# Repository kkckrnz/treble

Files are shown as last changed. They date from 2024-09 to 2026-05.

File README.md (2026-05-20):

# Treble
Treble keyboard is a 42 key, low profile choc v1, monoblock, moderate column staggered, wireless/wired mechanical keyboard powered by pro micro compatible MCU board. It is designed with [ergogen](https://github.com/ergogen/ergogen), the ergonomic keyboard generator.

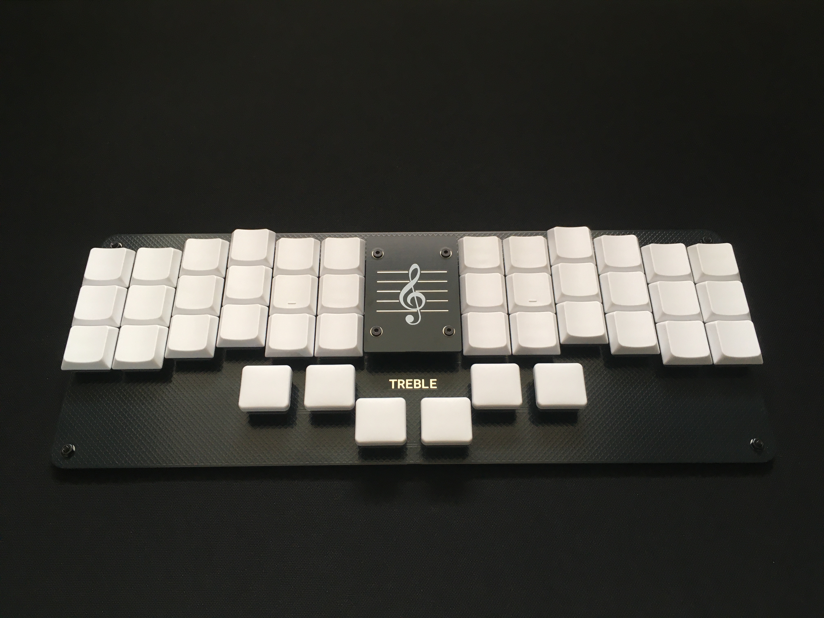
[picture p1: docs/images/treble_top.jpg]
treble_top

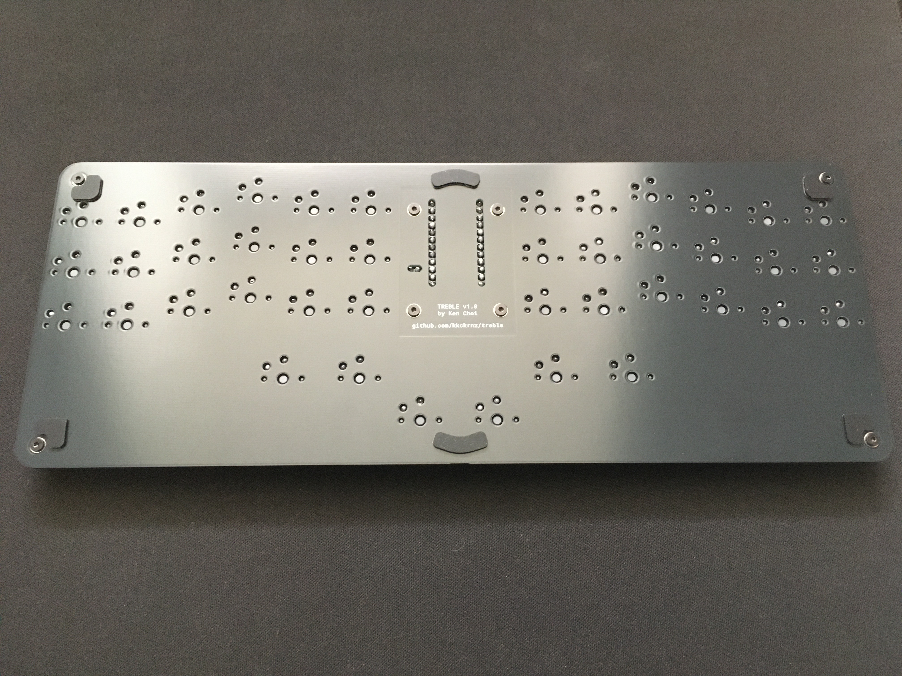
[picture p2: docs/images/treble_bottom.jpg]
treble_bottom

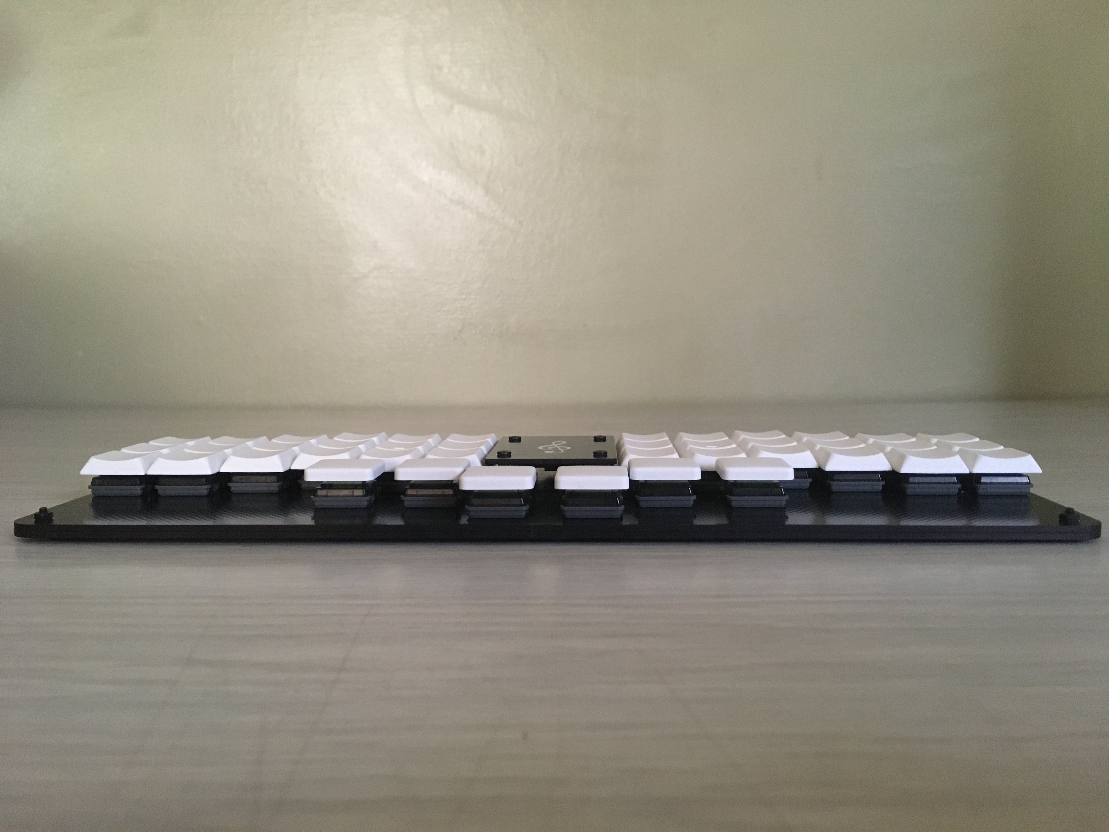
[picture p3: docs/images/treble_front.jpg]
treble_front


The sandwich PCB design concept came from [Horizon keyboard](https://github.com/skarrmann/horizon). Bottom plate cutouts for through-hole pins makes it so that keyboard can be put on any surface, and the cover plate hides all the other internal components. Overall, this design makes the keyboard clean, low profile and look more finished without needing a dedicated case.

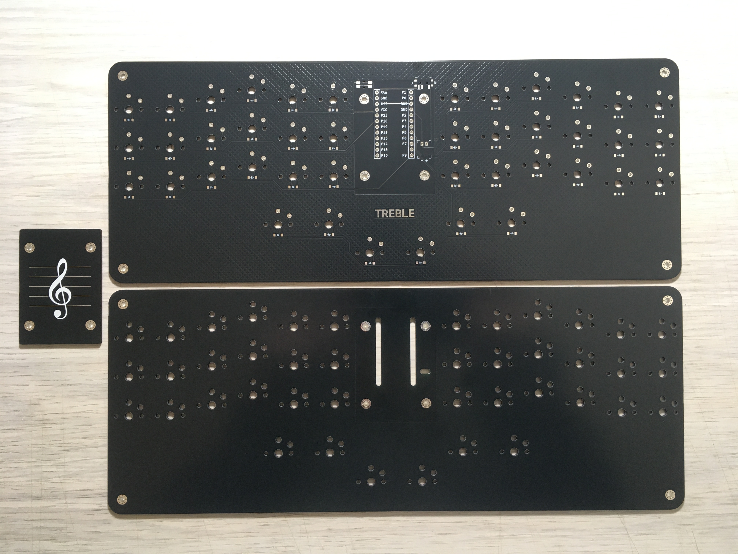
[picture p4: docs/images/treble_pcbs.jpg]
treble_pcbs


## Features
- Rectangular design for improved stability; easier to place on your lap or a laptop
- Low profile: total height is about 15mm tall
- Compact: overall size smaller than Apple Magic Keyboard
- Column staggered: mildly staggered so it's easy transition from row staggered keyboard yet it provides more comfortable typing experience
- 6 thumb keys: enough thumb keys for switching to different layers
- PCBs-for-case design
- Wireless/Wired depending on your preference

## Bill of Materials

| **Part** | **Quantity** | **Notes** |
| --- | --- | --- |
| **Main PCB** | 1 | treble_vx.x.zip |
| **Cover plate PCB** | 1 | treble_vx.x_cover_plate.zip |
| **Bottom plate PCB** | 1 | treble_vx.x_bottom_plate.zip |
| **MCU board** | 1 | Pro Micro compatible board |
| **Machine Sockets** | 2 | Mill-Max 310 |
| **Machine Socket Pins** | 24 | Mill-Max 3320 |
| **Key switches** | 42 | Choc v1 |
| **Keycaps** | 42 | Choc v1 compatible |
| **Diodes** | 42 | 1N4148 SOD-123 |
| **Reset switch** | 1 | EVQPU |
| **Power switch** | 1 | MSK-12C02 |
| **JST connector (female)** | 1 | S2B-PH-K-S |
| **JST connector (male)** | 1 | |
| **Battery** | 1 | 301230 110mAh 3.7V LiPo |
| **M2 6mm screws** | 12 | |
| **M2 nuts** | 4 | |
| **M2 8mm standoffs (female-female)** | 4 | |
| **Rubber feet** | 6 | |

- Male JST connector is only needed if the battery doesn't come with it
- You don't need Power switch, JST connector, and Battery if you build a wired keyboard

## Printable Treble
Download [Treble-A4.pdf](/docs/treble-A4.pdf) and print it (scale at 100%). Test the keyboard layout with your own hands.

## PCB order guide
1. Download gerber files from *Releases* on sidebar
2. Submit gerber files to PCB manufacturer
3. Select manufacturing options
4. Order

### JLCPCB manufacturing options
Most options are default. Changed options in *italic*:
- Base Material: FR-4
- Layers: 2
- Dimensions: (automatically filled in)
- PCB Qty: 5
- Product Type: Industrial/Consumer electronics
- Different Design: 1
- Delivery Format: Single PCB
- PCB Thickness: 1.6
- PCB Color: *Black*
- Silkscreen: White
- Surface Finish: *LeadFree HASL*
- Outer Copper Weight: 1 oz
- Via Covering: Tented
- Min via hole size/diameter: 0.3mm/(0.4/0.45mm)
- Board Outline Tolerance: ±0.2mm(Regular)
- Confirm Production file: No
- Mark on PCB: *Remove Mark*
- Electrical Test: Flying Probe Fully Test
- Gold Fingers: No
- Castellated Holes: No
- Edge Plating: No

I recommend **LeadFree HASL** option because you will be handling the keyboard directly without a case. Pick the PCB color of your choice. **Remove Mark** so you won't see random number printed on the PCB.

## Firmware
### ZMK
1. Setup GitHub Repo by following [ZMK documentation](https://zmk.dev/docs/user-setup#github-repo)
2. Setup User Config by following [ZMK documentation](https://zmk.dev/docs/user-setup#user-config-setup-script)	
3. Copy & Paste `/boards`, `/config`, and `build.yaml` from [zmk-config folder](/firmware/zmk-config) in this repo to zmk-config folder in your repo
4. Customise `treble.keymap` and `treble.conf` files in `/config` however you like it. Then push changes to your repo
```
git add .
git commit -m "commit message"
git push -u origin main
```
5. Install firmware by following [ZMK documentation](https://zmk.dev/docs/user-setup#installing-the-firmware)

- If you use MCU board other than nice!nano v2, then you will have to edit `build.yaml` file.
- [Precompiled firmware](/firmware/treble-nice_nano_v2-zmk.uf2.zip) is also available.
- There's [video guide](https://www.youtube.com/watch?v=O_urj-rF3bQ) by Joe Scotto if you would rather setup from scratch.

### Other Firmware
Since the keyboard is pro micro compatible it should be able to run QMK & KMK as well (not tested).

## Build guide
Follow [Build Guide](docs/treble_build_guide.md) to assemble the keyboard.

## Feedback
For any issues or questions please let me know.

If you have built and enjoyed the keyboard, consider supporting me.

Future development ideas:
- QMK & KMK firmware
- Hot swap switch support
- Low profile case
- MX version



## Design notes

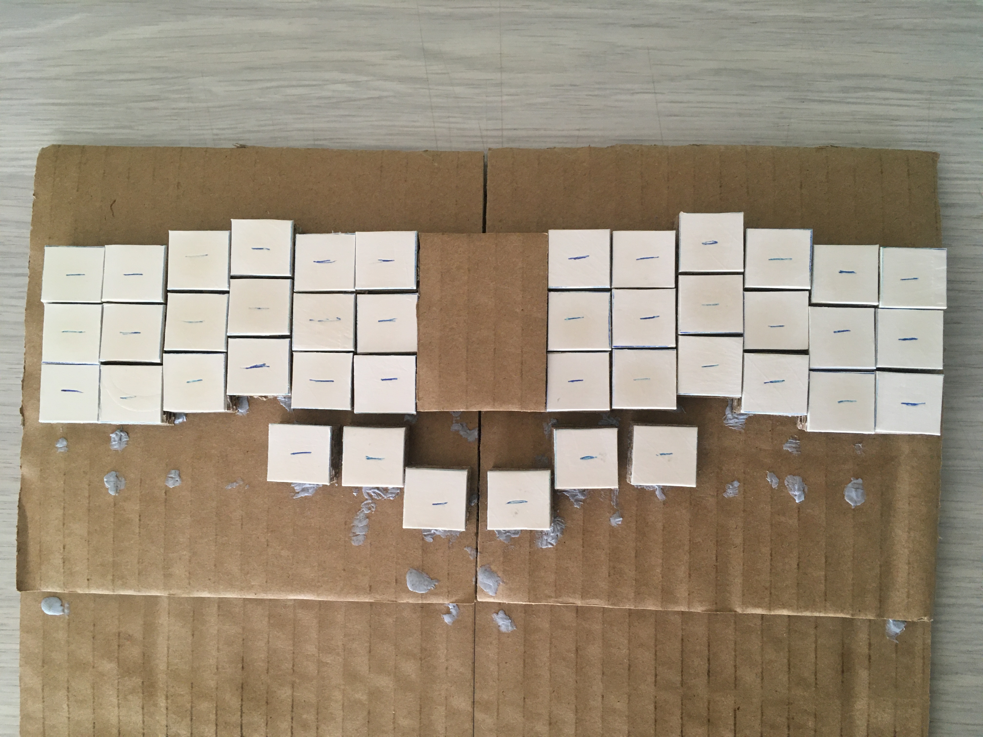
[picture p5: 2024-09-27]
docs/images/prototype.jpg

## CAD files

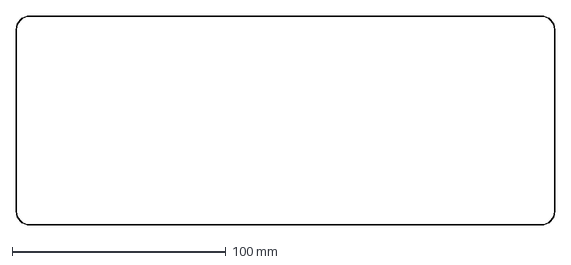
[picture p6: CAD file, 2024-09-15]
ergogen/output/outlines/board.dxf
252.0 x 97.8 mm

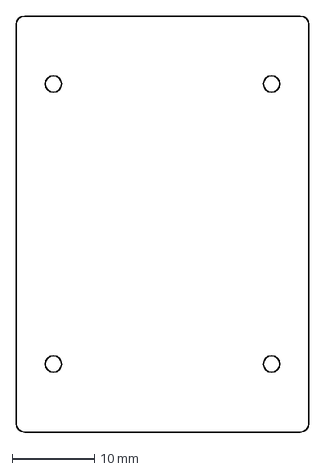
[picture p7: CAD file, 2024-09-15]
ergogen/output/outlines/cover_plate_view.dxf
35.5 x 50.5 mm

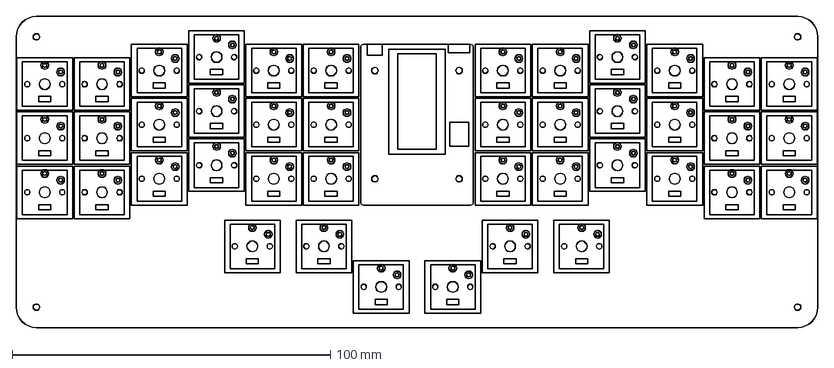
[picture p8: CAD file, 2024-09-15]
ergogen/output/outlines/everything.dxf
252.0 x 97.8 mm

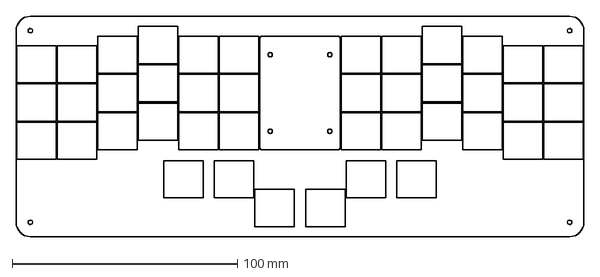
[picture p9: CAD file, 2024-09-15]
ergogen/output/outlines/keyboard_view.dxf
252.0 x 97.8 mm

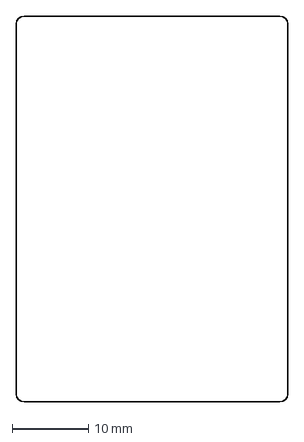
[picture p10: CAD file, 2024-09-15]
ergogen/output/outlines/cover.dxf
35.5 x 50.5 mm

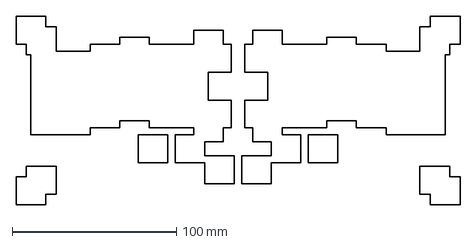
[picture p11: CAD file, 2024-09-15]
ergogen/output/outlines/raw.dxf
270.0 x 114.8 mm

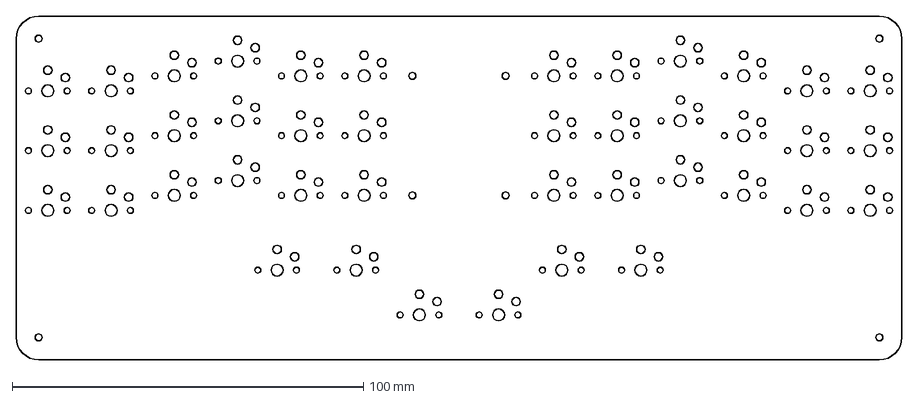
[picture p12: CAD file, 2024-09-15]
ergogen/output/outlines/bottom_plate_view.dxf
252.0 x 97.8 mm

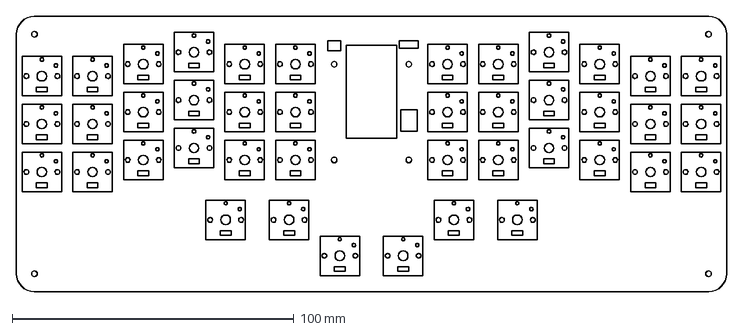
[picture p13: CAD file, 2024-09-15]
ergogen/output/outlines/board_view.dxf
252.0 x 97.8 mm

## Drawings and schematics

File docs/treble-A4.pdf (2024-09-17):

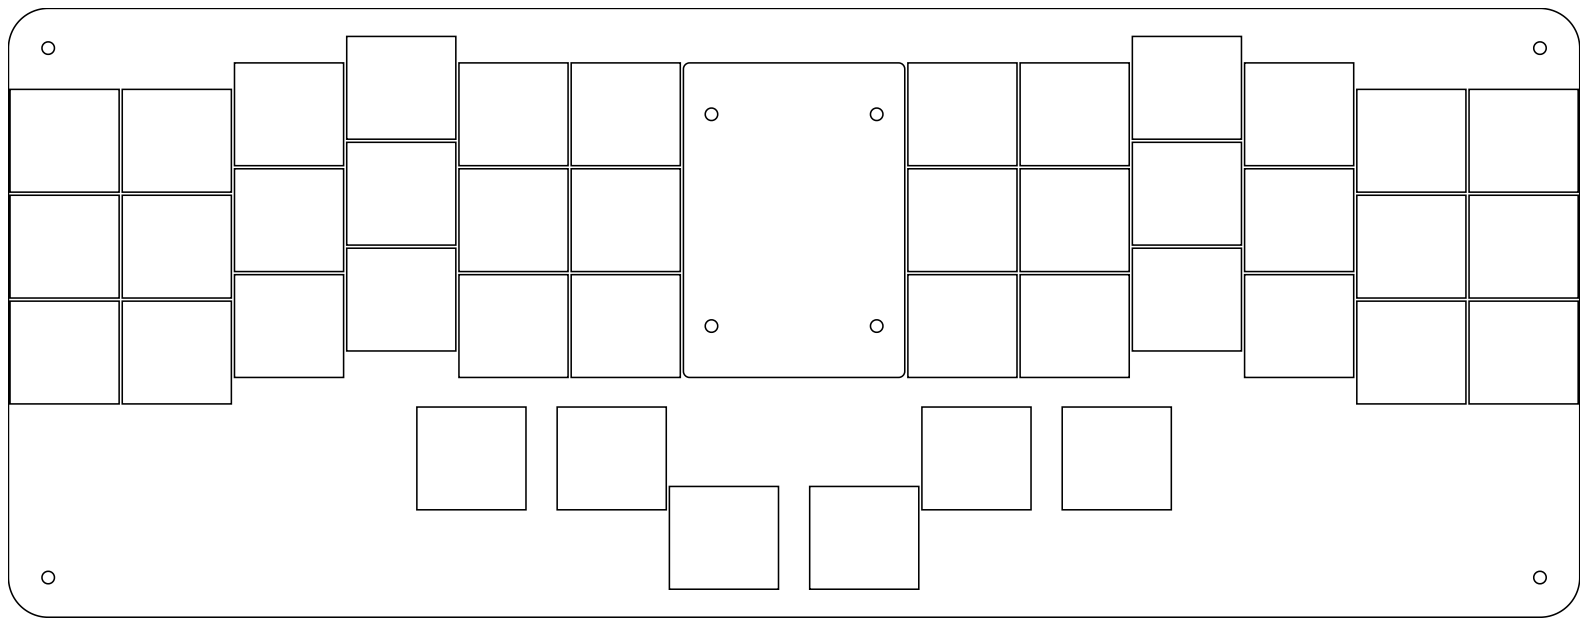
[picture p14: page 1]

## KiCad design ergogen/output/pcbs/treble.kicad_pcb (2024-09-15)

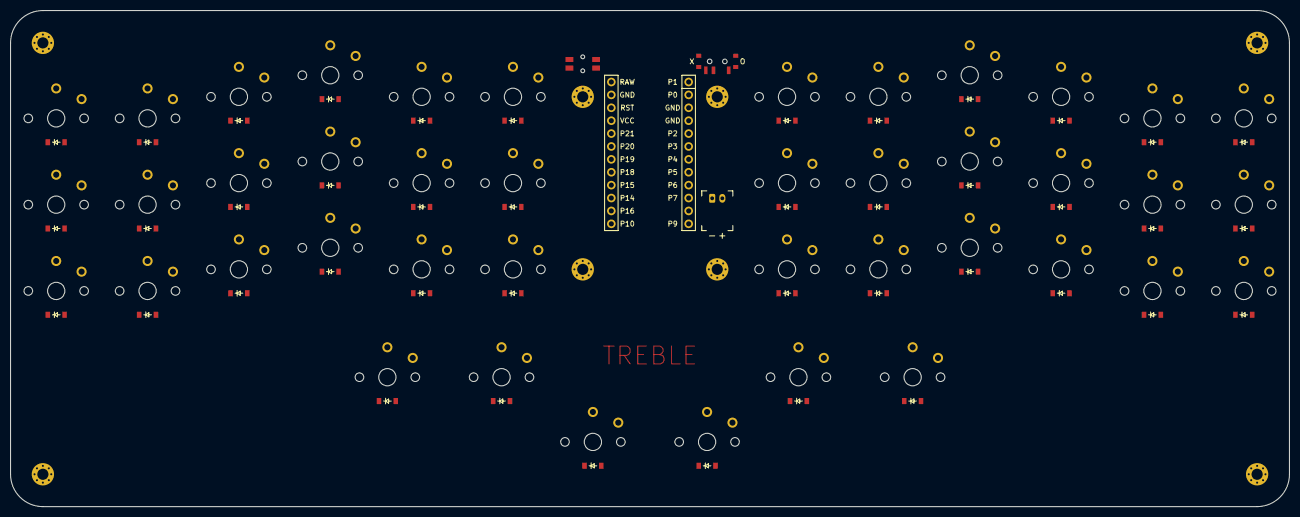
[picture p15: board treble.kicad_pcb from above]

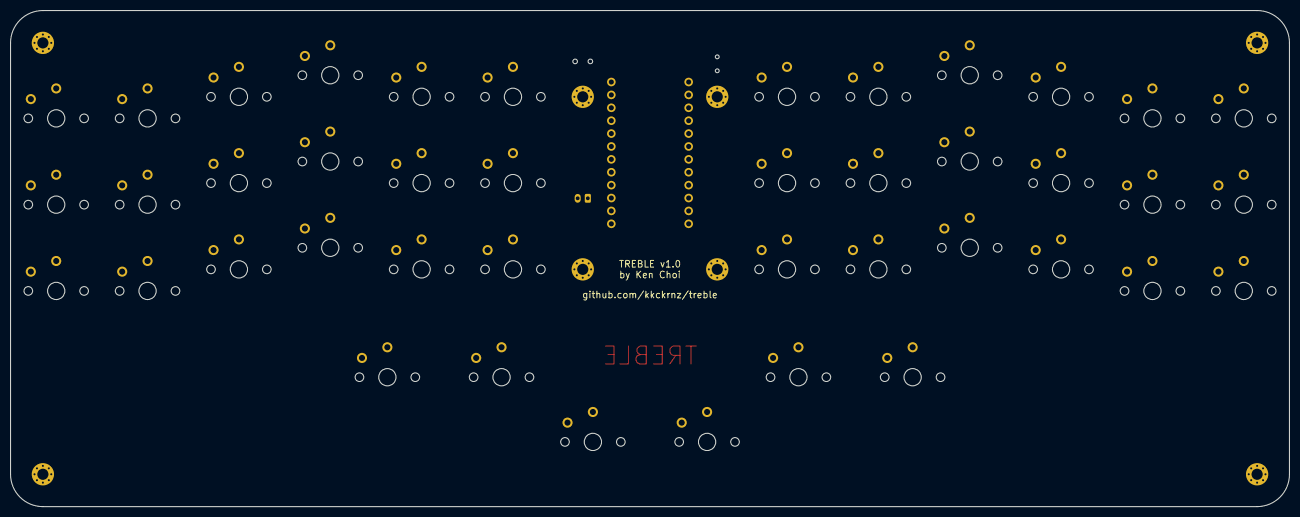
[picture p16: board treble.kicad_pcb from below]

Board: 2 copper layers, 252.0 x 97.8 mm, 141 parts (42 on the bottom side), 59 nets, no tracks yet.

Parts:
CJ1: CutoutMCU
CM1: CutoutMCU
CS1, CS2, CS3, CS4, CS5, CS6, CS7, CS8, CS9, CS10, CS11, CS12, CS13, CS14, CS15, CS16, CS17, CS18, CS19, CS20, CS21, CS22, CS23, CS24, CS25, CS26, CS27, CS28, CS29, CS30, CS31, CS32, CS33, CS34, CS35, CS36, CS37, CS38, CS39, CS40, CS41, CS42: CutoutSwitch
D1, D2, D3, D4, D5, D6, D7, D8, D9, D10, D11, D12, D13, D14, D15, D16, D17, D18, D19, D20, D21, D22, D23, D24, D25, D26, D27, D28, D29, D30, D31, D32, D33, D34, D35, D36, D37, D38, D39, D40, D41, D42: diode_tht_sod123
H1, H2, H3, H4, H5, H6, H7, H8: MountingHole_2.2mm_M2_Pad_Via
JST1: battery_connector_jst_ph_2
MCU1: mcu_nice_nano
PWR1: power_switch_smd_side
RA1: RuledArea
RST1: reset_switch_smd_side
S1, S2, S3, S4, S5, S6, S7, S8, S9, S10, S11, S12, S13, S14, S15, S16, S17, S18, S19, S20, S21, S22, S23, S24, S25, S26, S27, S28, S29, S30, S31, S32, S33, S34, S35, S36, S37, S38, S39, S40, S41, S42: switch_choc_v1_v2

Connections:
BAT_P: JST1.2, PWR1.1
GND: JST1.1, MCU1.3, MCU1.4, MCU1.23, RST1.1, RST1.3
P5: D24.1, D27.1, D30.1, D33.1, D36.1, D39.1, MCU1.8
P6: D23.1, D26.1, D29.1, D32.1, D35.1, D38.1, MCU1.9
P7: D22.1, D25.1, D28.1, D31.1, D34.1, D37.1, MCU1.10
P8: D19.1, D20.1, D21.1, D40.1, D41.1, D42.1, MCU1.11
P9: D1.1, D4.1, D7.1, D10.1, D13.1, D16.1, MCU1.12
P10: MCU1.13, S1.2, S2.2, S3.2, S37.2, S38.2, S39.2, S42.2
P14: MCU1.15, S7.2, S8.2, S9.2, S31.2, S32.2, S33.2, S40.2
P15: MCU1.16, S10.2, S11.2, S12.2, S19.2, S28.2, S29.2, S30.2
P16: MCU1.14, S4.2, S5.2, S6.2, S34.2, S35.2, S36.2, S41.2
P18: MCU1.17, S13.2, S14.2, S15.2, S20.2, S25.2, S26.2, S27.2
P19: MCU1.18, S16.2, S17.2, S18.2, S21.2, S22.2, S23.2, S24.2
P20: D2.1, D5.1, D8.1, D11.1, D14.1, D17.1, MCU1.19
P21: D3.1, D6.1, D9.1, D12.1, D15.1, D18.1, MCU1.20
RAW: MCU1.24, PWR1.2
RST: MCU1.22, RST1.2, RST1.4
home_thumb: D20.2, S20.1
index_bottom: D13.2, S13.1
index_home: D14.2, S14.1
index_top: D15.2, S15.1
inner_bottom: D16.2, S16.1
inner_home: D17.2, S17.1
inner_thumb: D19.2, S19.1
inner_top: D18.2, S18.1
middle_bottom: D10.2, S10.1
middle_home: D11.2, S11.1
middle_top: D12.2, S12.1
mirror_home_thumb: D41.2, S41.1
mirror_index_bottom: D34.2, S34.1
mirror_index_home: D35.2, S35.1
mirror_index_top: D36.2, S36.1
mirror_inner_bottom: D37.2, S37.1
mirror_inner_home: D38.2, S38.1
mirror_inner_thumb: D40.2, S40.1
mirror_inner_top: D39.2, S39.1
mirror_middle_bottom: D31.2, S31.1
mirror_middle_home: D32.2, S32.1
mirror_middle_top: D33.2, S33.1
mirror_outer_bottom: D22.2, S22.1
mirror_outer_home: D23.2, S23.1
mirror_outer_thumb: D42.2, S42.1
mirror_outer_top: D24.2, S24.1
mirror_pinky_bottom: D25.2, S25.1
mirror_pinky_home: D26.2, S26.1
mirror_pinky_top: D27.2, S27.1
mirror_ring_bottom: D28.2, S28.1
mirror_ring_home: D29.2, S29.1
mirror_ring_top: D30.2, S30.1
outer_bottom: D1.2, S1.1
outer_home: D2.2, S2.1
outer_thumb: D21.2, S21.1
outer_top: D3.2, S3.1
pinky_bottom: D4.2, S4.1
pinky_home: D5.2, S5.1
pinky_top: D6.2, S6.1
ring_bottom: D7.2, S7.1
ring_home: D8.2, S8.1
ring_top: D9.2, S9.1

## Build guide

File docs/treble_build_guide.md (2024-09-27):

# Treble Build Guide
## Build overview
1. SMD components
2. Through-hole components
3. Testing
4. Key switches & Keycaps
5. Assembly

## General Tips
- Pads and pins connected to GND and Battery Positive are more difficult to solder. Consider increasing temperature for those pads and pins.
- Flux helps especially on those hard-to-solder pins and pads.
- I used 0.3mm solder wire for SMD components and 0.8mm wire for the rest.

## 1. SMD components
### Diodes
1. Add solder to one pad of the PCB
2. Make sure the line on diode marking is aligned with the line marked on the PCB
3. Hold the diode in place using a pair of tweezers
4. Apply heat on the pad to connect diode to the PCB
5. Add solder to the other pad

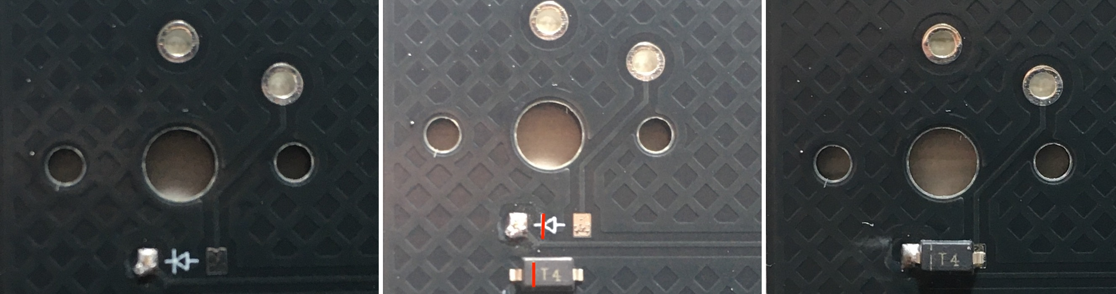
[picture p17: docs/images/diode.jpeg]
diode


### Power & Reset switch
1. Add solder to the pads on one side
2. Hold the switch in place using a pair of tweezers
3. Heat the pads to connect the switch to the PCB
4. Solder the rest of the pads

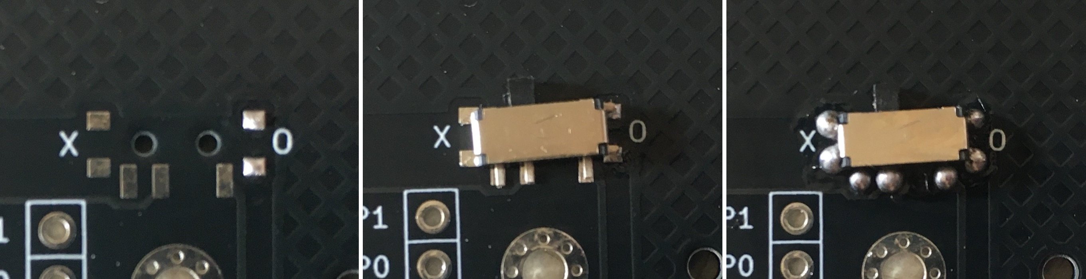
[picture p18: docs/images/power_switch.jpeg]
power_switch


## 2. Through-hole components
### MCU board
Soldering to the PCB:
1. Insert socket into the top of the PCB
2. Flip the PCB and solder the top and bottom pins
3. Solder the rest of the pins

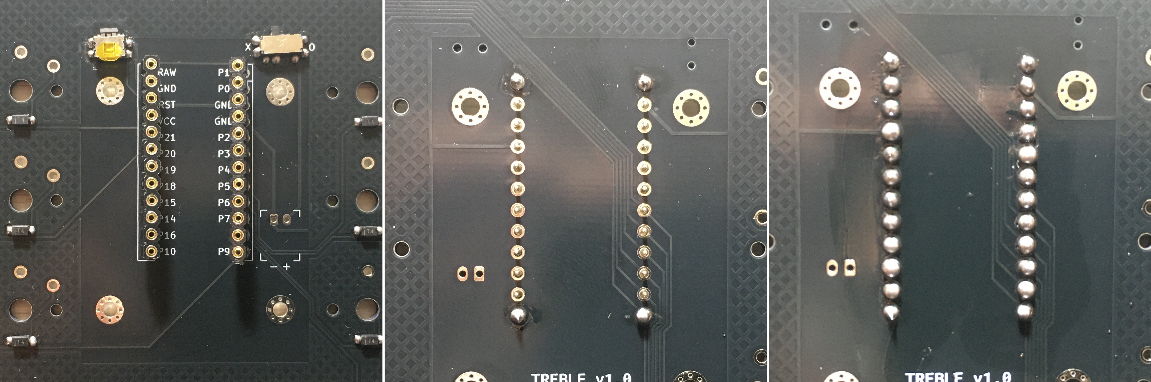
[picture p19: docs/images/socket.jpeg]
socket


Insert pins:
1. Place kapton tape over the top of each socket
2. Poke pins through the tape
3. Pins sit about 2mm above the top of the socket when fully inserted.

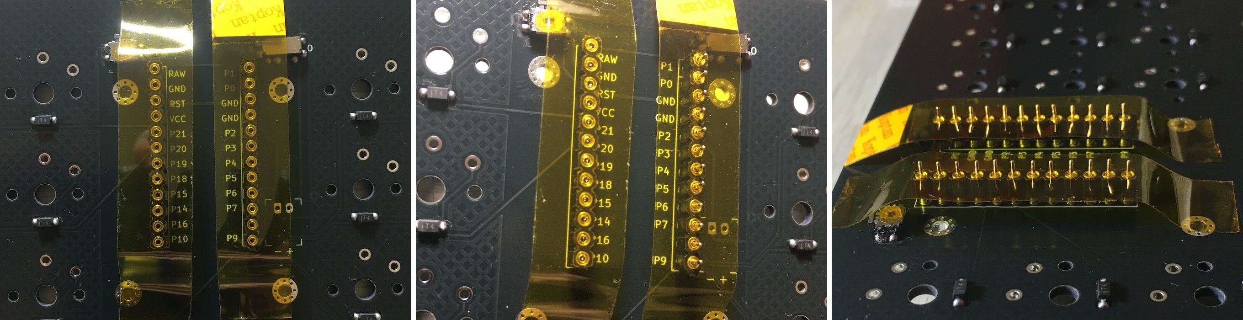
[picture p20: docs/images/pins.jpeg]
pins


Solder MCU board:
1. Place MCU face down on the pins
2. Ensure B+/B- do not have pins in them
3. Solder each corner pin
4. Solder the rest of the pins
5. Remove MCU and kapton tape

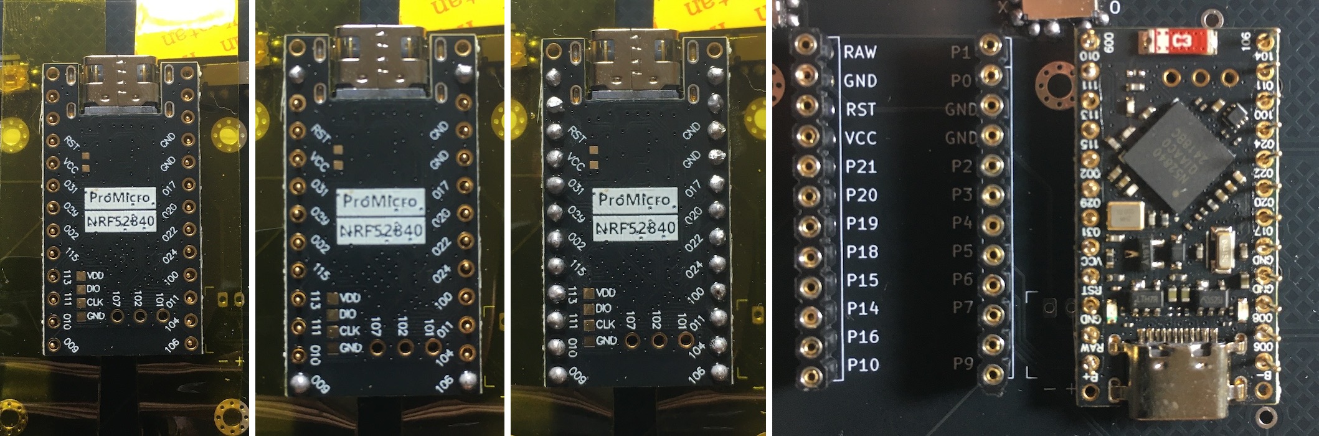
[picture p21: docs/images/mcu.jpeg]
muc_board


### JST connector
#### JST connector (Female)
Note: if JST connector pins are longer than 3.2mm, you may want to cut them down slightly before soldering.
1. Insert the female JST connector into the PCB
2. Flip over the PCB and solder the pins

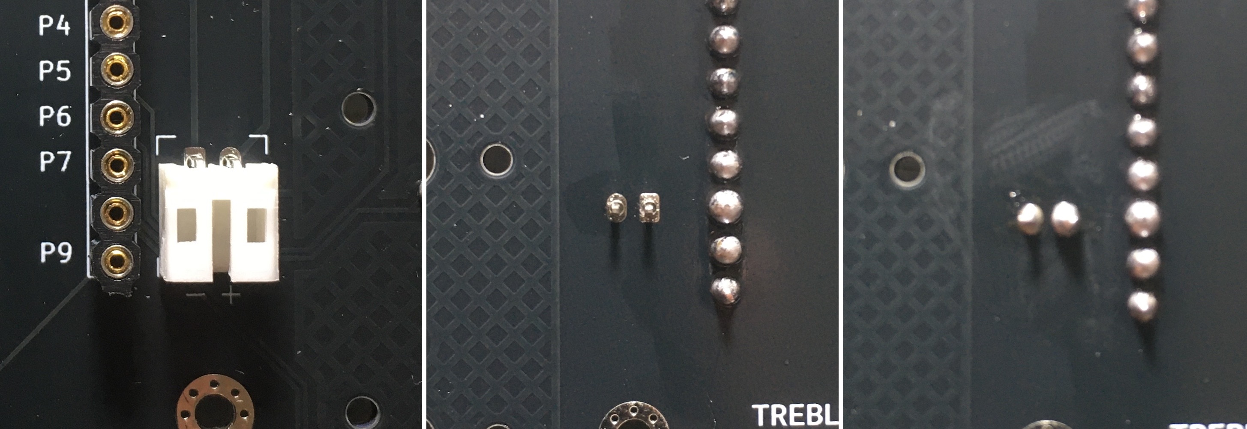
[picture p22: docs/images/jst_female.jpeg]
jst_female


#### JST connector (Male)
1. Follow this [video guide](https://www.youtube.com/watch?v=UD1h8ug3wQQ) to install connector to the battery
2. Check battery polarity. Positive wire should be inserted to the positive female JST connector pin marked on the PCB

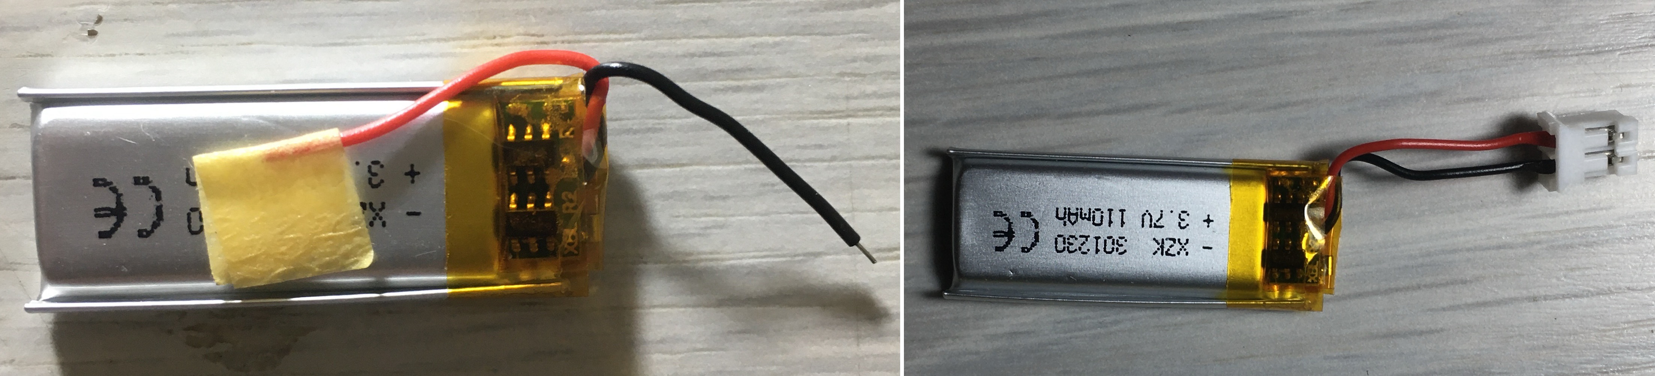
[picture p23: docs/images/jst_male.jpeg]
jst_male


#### Battery
1. Make sure the power switch is OFF (marked **X** on the PCB)
2. Insert the male JST connector to the female connector
3. Put the battery in place
4. Socket the MCU board

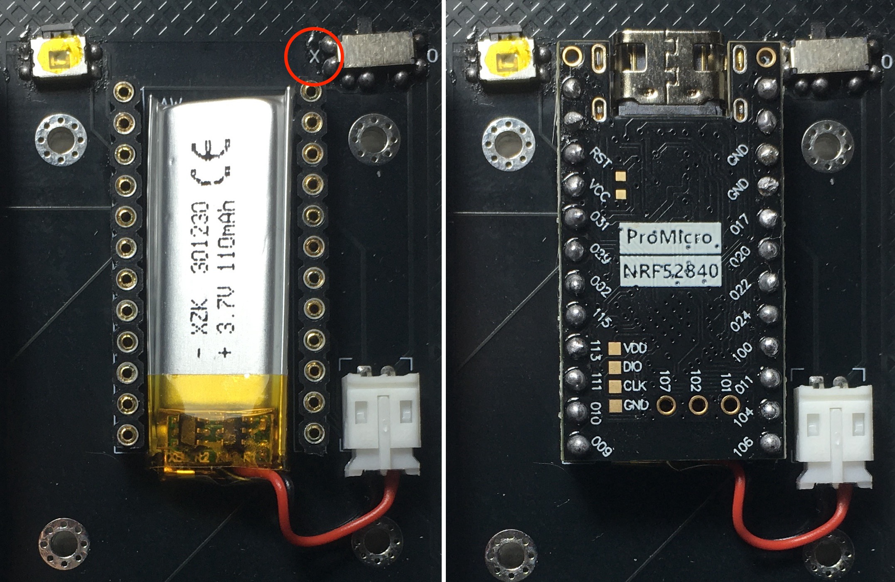
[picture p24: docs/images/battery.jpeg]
battery


## 3. Testing
1. Flash the firmware.
2. Go to [keyboard tester](https://www.keyboardtester.com/tester.html) and simulate key press using a pair of tweezers.

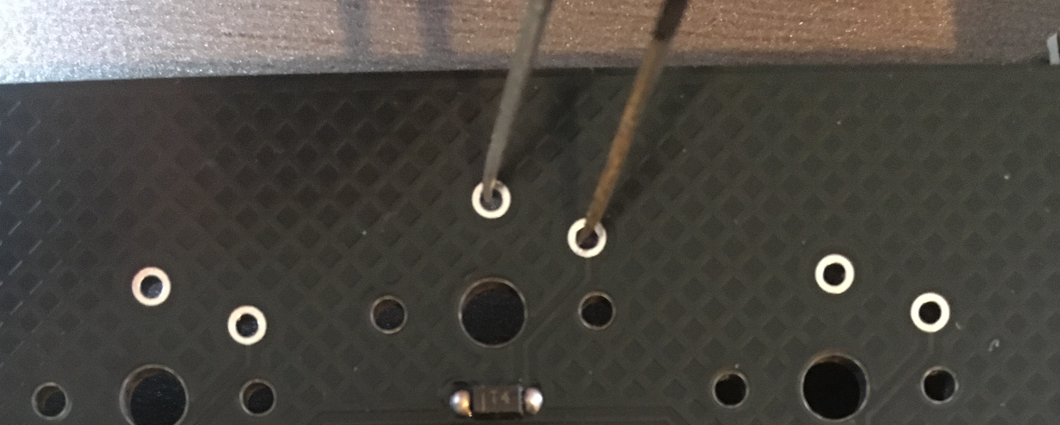
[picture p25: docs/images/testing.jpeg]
testing


## 4. Key switches & Keycaps
1. Insert switches into the PCB
2. Place keycaps on the switches
3. Flip the PCB and solder switch pins

switches-keycaps

## 5. Assembly
1. Put the main PCB and bottom plate together (four corners mounting holes)
2. Mount the standoffs
3. Place the cover plate on top of standoffs
4. Put rubber feet on the bottom

assembly

## Finished keyboard

treble_top

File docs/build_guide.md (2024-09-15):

# Build Guide
## Build overview
1. SMD components
2. Through-hole components
3. Testing
4. Key switches & Keycaps
5. Assembly

## 1. SMD components
### Diodes
1. Add solder to one pad of the PCB
2. Make sure the line on diode marking is aligned with the line marked on the PCB
3. Hold the diode in place using a pair of tweezers
4. Apply heat on the pad to connect diode to the PCB
5. Add solder to the other pad

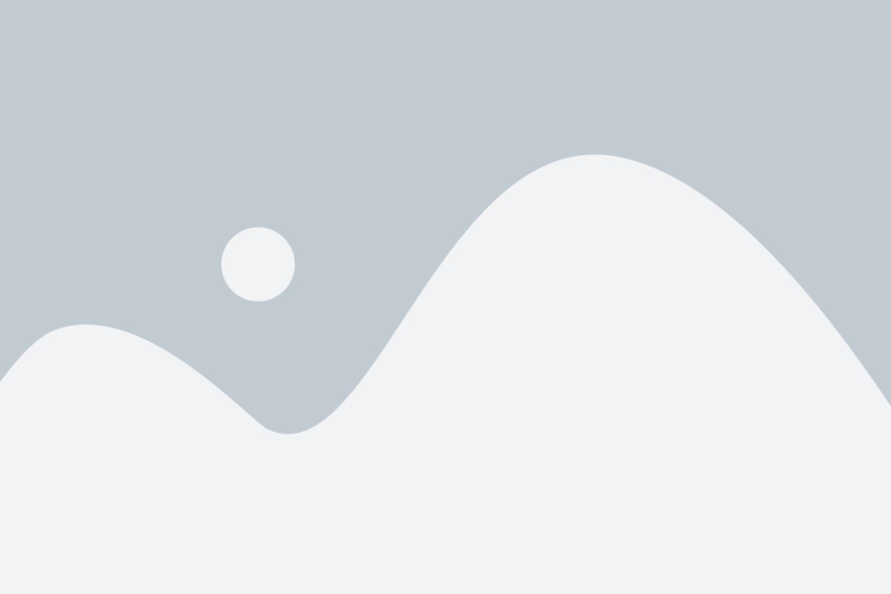
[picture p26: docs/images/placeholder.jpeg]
diode


### Power & Reset switch
1. Add solder to the pads on one side
2. Hold the switch in place using a pair of tweezers
3. Heat the pads to connect the switch to the PCB
4. Solder the rest of the pads

power_switch

## 2. Through-hole components
### MCU board
Soldering to the PCB:
1. Insert socket into the top of the PCB
2. Flip the PCB and solder the top and bottom pins
3. Solder the rest of the pins

sockets

Insert pins:
1. Place kapton tape over the top of each socket
2. Poke pins through the tape
3. Pins sit about 2mm above the top of the socket when fully inserted.

pins

Solder MCU board:
1. Place MCU face down on the pins
2. Ensure B+/B- do not have pins in them
3. Solder each corner pin
4. Solder the rest of the pins
5. Remove MCU and kapton tape

muc_board

### JST connector
#### JST female connector
1. Insert the female JST connector into the PCB
2. Flip over the PCB and solder the pins 

jst_female

#### (optional) JST male connector
1. Follow this [video guide](https://www.youtube.com/watch?v=UD1h8ug3wQQ) to install connector to the battery
2. Positive wire should be inserted to the positive female JST connector pin marked on the PCB

jst_male

#### Battery
1. Make sure the power switch is OFF (marked **X** on the PCB)
2. Insert the male JST connector to the female connector
3. Put the battery in place
4. Socket the MCU board

battery

## 3. Testing
1. Follow [ZMK Firmware Build Guide](/docs/zmk_firmware_build_guide.md) to create and flash the firmware.
2. Go to [keyboard tester](https://www.keyboardtester.com/tester.html) and simulate key press using a pair of tweezers.

testing

## 4. Key switches & Keycaps
1. Insert switches into the PCB
2. Place keycaps on the switches
3. Flip the PCB and solder switch pins

switches-keycaps

## 5. Assembly
1. Put the main PCB and bottom plate together (four corners mounting holes)
2. Mount the standoffs
3. Place the cover plate on top of standoffs
4. Put rubber feet on the bottom

assembly

## Finished keyboard

treble_front

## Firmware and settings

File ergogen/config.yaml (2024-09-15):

meta:
  engine: 4.1.0
  version: 1.0
  author: Ken Choi

########## footprints ##########
# mcu: mcu_nice_nano (nice!nano compatible)
# switch: switch_choc_v1_v2
# reset: reset_switch_smd_side (EVQPU)
# power: power_switch_smd_side (MSK-12C02)
# jst: battery_connector_jst_ph_2 (S2B-PH-K-S(LF)(SN))
# diode: diode_tht_sod123 (SOD123 1N4148W)
# mounting hole: mountinghole_m2_via

# mcu cutout: cutout_mcu
# switch cutout: cutout_switch
# jst cutout: cutout_jst

# filled zone: utility_filled_zone
# ruled area: utility_ruled_area
# text: utility_text
# logo: logo_treble

########## units ##########
units:
  # custom preview variables for choc keycaps
  $default_width: cx
  $default_height: cy

  # key spacing
  kx: 1cx
  ky: 1cy

  # keycap
  cap_w: 17.5
  cap_h: 16.5

  # column stagger
  c_matrix_pinky_ring: 0.25ky
  c_matrix_ring_middle: 0.25ky
  c_matrix_middle_index: 0.25ky
  c_matrix_cluster: 0
  c_cluster_home_outer: 0.75ky

  # row stagger
  r_mirror: 0.125kx
  r_cluster_inner_home: 0.25kx
  r_matrix_cluster: 7kx - 3kx - r_mirror - r_cluster_inner_home 

  # board edge border
  edge_border_x: 0
  edge_border_y: 0.25ky

  # plate mounting hole position from board corner
  plate_mounting_hole_distance: ((c_matrix_pinky_ring + c_matrix_ring_middle) + edge_border_y)/2

  # dimensions 
  board_h: 4ky + c_matrix_pinky_ring + c_matrix_ring_middle + c_matrix_cluster + c_cluster_home_outer + 2*edge_border_y

  cover_w: 2kx
  cover_h: 3ky

  mcu_w: 17.78 
  mcu_h: 33.08

  reset_w: 4.7
  reset_h: 3.5

  power_w: 6.7 # MSK-12C02: 6.65
  power_h: 2.6 # MSK-12C02: 2.7

  jst_w: 5.9
  jst_h: 7.6

  diode_w: 3.85 # switch led hole width: 5
  diode_h: 1.65 # switch led hole height: 3.15

  mounting_hole_r: 1

  battery_w: 12 # 301230 lipo battery
  battery_h: 30

########## points ##########
points:
  key:
    spread: kx
    padding: ky
  
  zones:
    # keys
    matrix:
      anchor:
        shift: [90, -150] # fix placement on KiCad sheet
      key.tags: switch
      columns:
        outer:
          key:
            column_net: P10
            mirror:
              tags: switch_mirror
              column_net: P19
        pinky:
          key:
            column_net: P16
            mirror:
              tags: switch_mirror
              column_net: P18
        ring:
          key:
            stagger: c_matrix_pinky_ring
            column_net: P14
            mirror:
              tags: switch_mirror
              column_net: P15
        middle:
          key:
            stagger: c_matrix_ring_middle
            column_net: P15
            mirror:
              tags: switch_mirror
              column_net: P14
        index:
          key:
            stagger: -c_matrix_middle_index
            column_net: P18
            mirror:
              tags: switch_mirror
              column_net: P16
        inner:
          key:
            column_net: P19
            mirror:
              tags: switch_mirror
              column_net: P10
      rows:
        bottom:
          row_net: P9
          mirror.row_net: P7
        home:
          row_net: P20
          mirror.row_net: P6
        top:
          row_net: P21
          mirror.row_net: P5

    cluster:
      key.tags: switch
      anchor:
        ref: matrix_outer_bottom
        shift: [r_matrix_cluster, -ky - c_matrix_cluster]
      columns:
        inner:
          key:
            column_net: P15
            mirror:
              tags: switch_mirror
              column_net: P14                    
        home:
          key:
            shift: [0.25kx, 0]
            column_net: P18
            mirror:
              tags: switch_mirror
              column_net: P16
        outer:
          key:
            stagger: -c_cluster_home_outer
            shift: [ 0.25kx, 0]
            column_net: P19
            mirror:
              tags: switch_mirror
              column_net: P10
      rows:
        thumb:
          row_net: P8
          mirror:
            row_net: P8

    # placeholder points for board, mcu cover, mounting holes
    board_placeholder:
      key.padding: board_h
      anchor:
        ref: matrix_middle_top
        shift: [-0.5kx - 3kx - edge_border_x, 0.5ky + edge_border_y - board_h]
      columns:
        single:
      rows:
        bottom:
        top:

    cover_placeholder:
      key.padding: cover_h
      anchor:
        ref: matrix_inner_bottom
        shift: [0.5kx, -0.5ky]
      columns:
        single:
      rows:
        bottom:
        top:
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

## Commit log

2024-09-15 upload all files
    [board.dxf, board_view.dxf, bottom_plate_view.dxf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]
2024-09-16 Rename treble_pcbs.JPG to treble_pcbs.jpg
    file format lower case
2024-09-16 added socket image
2024-09-27 fix jst pin length
